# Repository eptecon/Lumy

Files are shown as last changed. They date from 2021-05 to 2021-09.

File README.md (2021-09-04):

Lumy: Smart Connected LED Lighting System
======

Lumy is a smart connected LED lighting system comprising multiple interconnectable modules.

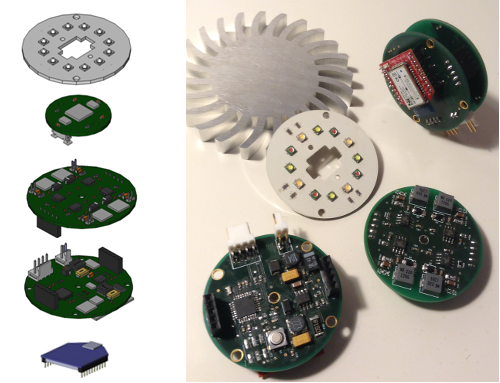
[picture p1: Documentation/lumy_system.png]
 

### Hardware

Lumy hardware comprises following modules:

- LumyCtrl: power supply, main microcontroller (ATMega328P) interface to WiFi module and interface to LED driver
- LumyDrv: 4x TI LM3404 LED driver with 1.2A output each
- LumyLight: LED carrier board, can be populated with up to 12 Cree high power LEDs arranged in 3 separate strings with up to 4 LEDs each
- LumySense: ambient light sensor TSL2591  

### Firmware

Lumy firmware is a simple bare metal C program running on the ATMega328P. It controls the brightness of connected LEDs over PWM inputs of the LED drivers
depending on sensor or user input. The user input is provided over a simple android app, which sends the data wirelessly over WiFi to the Lumy system.

---

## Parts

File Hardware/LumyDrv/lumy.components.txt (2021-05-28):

Stückliste exportiert aus C:/Users/Murzilka/Projektdaten/Eagle/Lumilabs/LumyDrv/lumy.sch am 13.10.2013 14:07:51

Bestückungsvariante: 

Bauteil Wert       Device     Package    Description                                                    
CB1     10n        C-EUC0603  C0603      CAPACITOR, European symbol                                     
CB2     10n        C-EUC0603  C0603      CAPACITOR, European symbol                                     
CB3     10n        C-EUC0603  C0603      CAPACITOR, European symbol                                     
CB4     10n        C-EUC0603  C0603      CAPACITOR, European symbol                                     
CBY1    100n       C-EUC0603  C0603      CAPACITOR, European symbol                                     
CBY2    100n       C-EUC0603  C0603      CAPACITOR, European symbol                                     
CBY3    100n       C-EUC0603  C0603      CAPACITOR, European symbol                                     
CBY4    100n       C-EUC0603  C0603      CAPACITOR, European symbol                                     
CI1     4µ7        C-EUC0603  C0603      CAPACITOR, European symbol                                     
CI2     4µ7        C-EUC0603  C0603      CAPACITOR, European symbol                                     
CI3     4µ7        C-EUC0603  C0603      CAPACITOR, European symbol                                     
CI4     4µ7        C-EUC0603  C0603      CAPACITOR, European symbol                                     
CO1     1µ         C-EUC1206  C1206      CAPACITOR, European symbol                                     
CO2     1µ         C-EUC1206  C1206      CAPACITOR, European symbol                                     
CO3     1µ         C-EUC1206  C1206      CAPACITOR, European symbol                                     
CO4     1µ         C-EUC1206  C1206      CAPACITOR, European symbol                                     
D1      MBRA340T3  MBRA340T3  SMA        Surface Mount Schottky Power Rectifier                         
D2      MBRA340T3  MBRA340T3  SMA        Surface Mount Schottky Power Rectifier                         
D3      MBRA340T3  MBRA340T3  SMA        Surface Mount Schottky Power Rectifier                         
D4      MBRA340T3  MBRA340T3  SMA        Surface Mount Schottky Power Rectifier                         
IC1     LM3404     LM3404     SO08       1A Constant Current Buck  Regulator for driving High Power LEDs
IC2     LM3404     LM3404     SO08       1A Constant Current Buck  Regulator for driving High Power LEDs
IC3     LM3404     LM3404     SO08       1A Constant Current Buck  Regulator for driving High Power LEDs
IC4     LM3404     LM3404     SO08       1A Constant Current Buck  Regulator for driving High Power LEDs
L1      22µ        DR73       DR73       High Power Density, High Efficiency, Shielded Inductors        
L2      22µ        DR73       DR73       High Power Density, High Efficiency, Shielded Inductors        
L3      22µ        DR73       DR73       High Power Density, High Efficiency, Shielded Inductors        
L4      22µ        DR73       DR73       High Power Density, High Efficiency, Shielded Inductors        
RON1    48k7       R-EU_R0805 R0805      RESISTOR, European symbol                                      
RON2    48k7       R-EU_R0805 R0805      RESISTOR, European symbol                                      
RON3    48k7       R-EU_R0805 R0805      RESISTOR, European symbol                                      
RON4    48k7       R-EU_R0805 R0805      RESISTOR, European symbol                                      
RSN1    0R33       R-EU_R1206 R1206      RESISTOR, European symbol                                      
RSN2    0R33       R-EU_R1206 R1206      RESISTOR, European symbol                                      
RSN3    0R33       R-EU_R1206 R1206      RESISTOR, European symbol                                      
RSN4    0R33       R-EU_R1206 R1206      RESISTOR, European symbol                                      
SV1                FE05-1     FE05-1     FEMALE HEADER                                                  
SV2                FE05-1     FE05-1     FEMALE HEADER                                                  
X10     87758-0216 87758-0216 87758-0216 2 Pin - 2mm Dual Row Single Wafer, Vertical T/H HDR            
X20     87758-0216 87758-0216 87758-0216 2 Pin - 2mm Dual Row Single Wafer, Vertical T/H HDR            
X30     87758-0216 87758-0216 87758-0216 2 Pin - 2mm Dual Row Single Wafer, Vertical T/H HDR            
X40     87758-0216 87758-0216 87758-0216 2 Pin - 2mm Dual Row Single Wafer, Vertical T/H HDR

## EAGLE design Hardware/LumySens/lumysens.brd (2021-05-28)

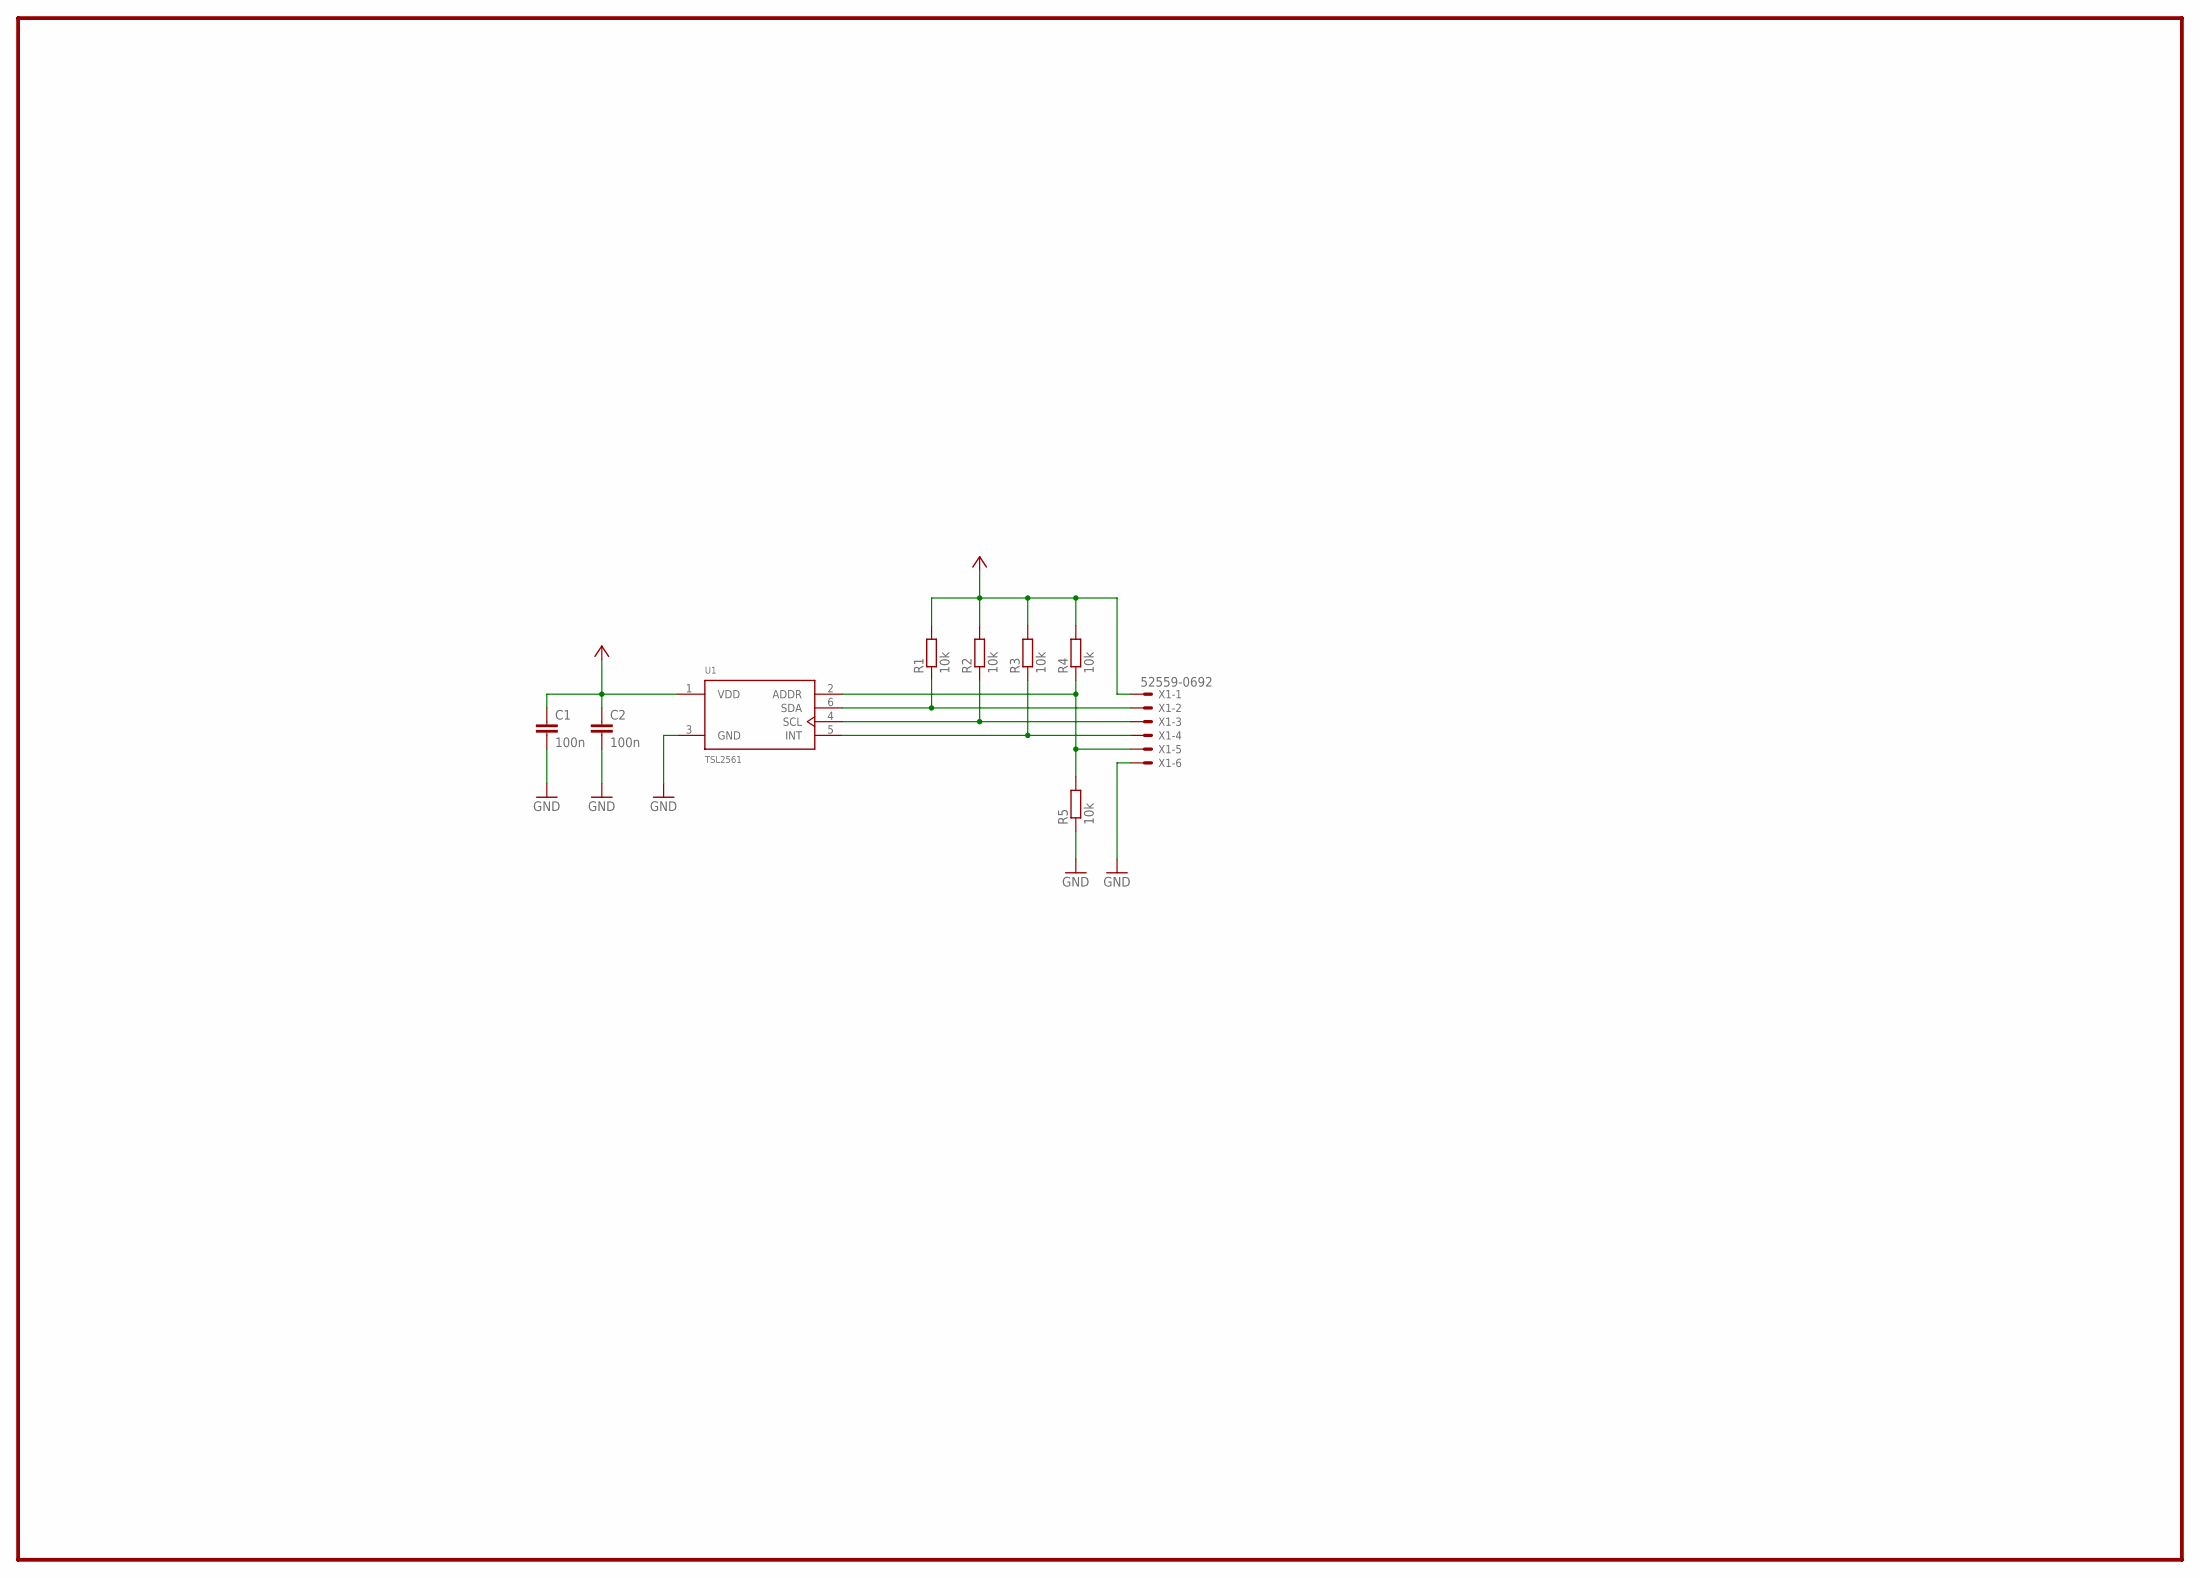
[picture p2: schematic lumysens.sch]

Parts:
C1, C2: 100n; C0603
R1, R2, R3, R4, R5: 10k; R0603
U1: TSL2561; TMB-6
X1: 52559-0692

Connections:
+3V3: C1.1, C2.1, R1.2, R2.2, R3.2, R4.2, U1.1 (VDD), X1.1
GND: C1.2, C2.2, R5.1, U1.3 (GND), X1.6
unnamed: R4.1, R5.2, U1.2 (ADDR), X1.5
unnamed: R1.1, U1.6 (SDA), X1.2
unnamed: R2.1, U1.4 (SCL), X1.3
unnamed: R3.1, U1.5 (INT), X1.4

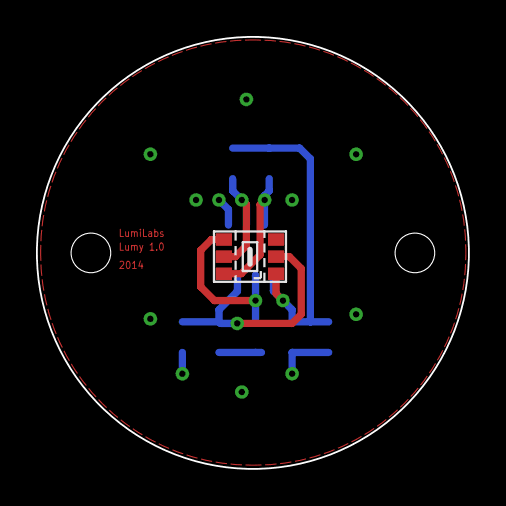
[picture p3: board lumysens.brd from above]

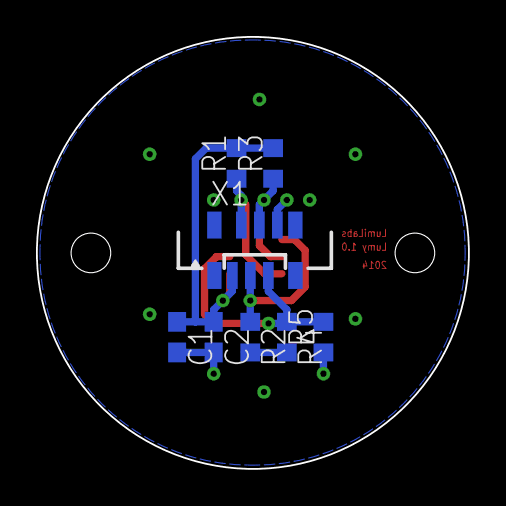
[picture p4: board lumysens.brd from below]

Board: 2 copper layers, 24.0 x 24.0 mm, 9 parts (8 on the bottom side), 6 nets.

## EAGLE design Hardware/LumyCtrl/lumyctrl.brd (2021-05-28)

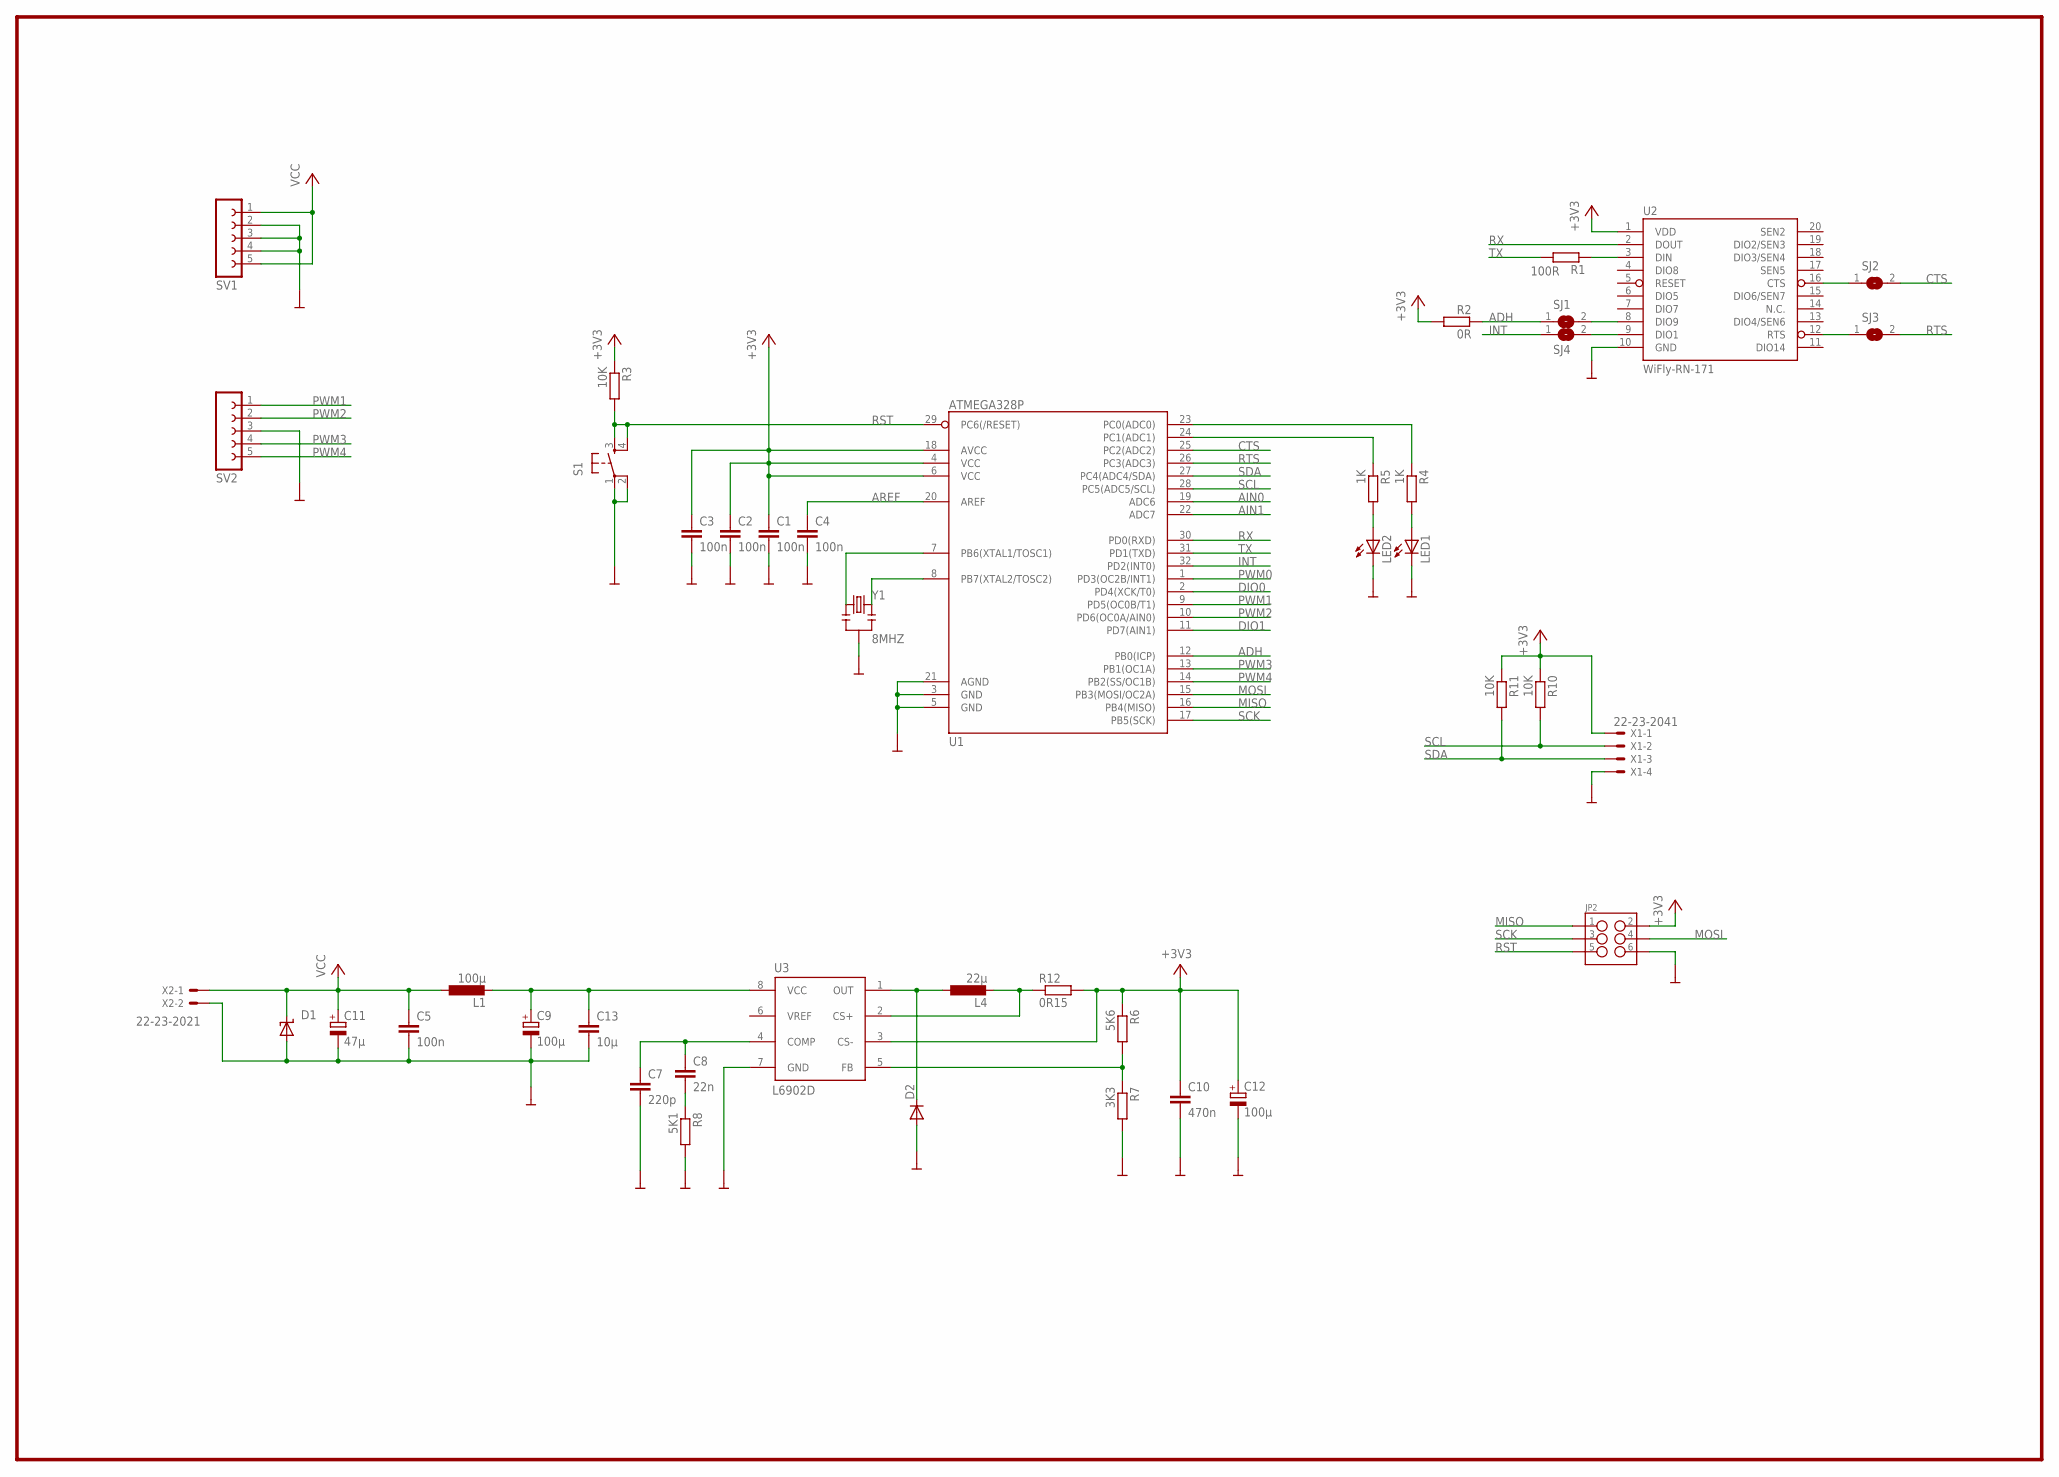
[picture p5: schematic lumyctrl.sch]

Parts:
C1, C2, C3, C4, C5: 100n; C0603
C7: 220p; C0603
C8: 22n; C0603
C9, C12: 100µ; SMC_C
C10: 470n; C0603
C11: 47µ; SMC_E
C13: 10µ; C1206
D1: SUPPRESSOR-SMBJ; SMBJ
D2: DIODESMA; SMA-DIODE
JP2: M03X2SMT; 2X3_SMT_POSTS
L1: 100µ; POWER-CHOKE_WE-TPC
L4: 22µ; POWER-CHOKE_WE-TPC
LED1, LED2: LEDCHIP-LED0603; CHIP-LED0603
R1: 100R; R0603
R2: 0R; R0603
R3, R10, R11: 10K; R0603
R4, R5: 1K; R0603
R6: 5K6; R0603
R7: 3K3; R0603
R8: 5K1; R0603
R12: 0R15; R2512
S1: TAC_SWITCHSMD; TACTILE_SWITCH_SMD
SJ1, SJ2, SJ3, SJ4: SJ
SV1, SV2: FE05-1
U1: ATMEGA328P; TQFP32-08
U2: WiFly-RN-171; XBEE-SMD
U3: L6902D; SO08
X1: 22-23-2041
X2: 22-23-2021
Y1: 8MHZ; RESONATOR-SMD

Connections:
+3V3: C1.1, C2.1, C3.1, C10.1, C12.+, JP2.2, R2.2, R3.1, R6.1, R10.1, R11.1, R12.2, U1.4 (VCC), U1.6 (VCC), U1.18 (AVCC), U2.1 (VDD), U3.3 (CS-), X1.1
ADH: R2.1, SJ1.1, U1.12 (PB0(ICP))
AIN0: U1.19 (ADC6)
AIN1: U1.22 (ADC7)
AREF: C4.1, U1.20 (AREF)
CTS: SJ2.2, U1.25 (PC2(ADC2))
DIO0: U1.2 (PD4(XCK/T0))
DIO1: U1.11 (PD7(AIN1))
GND: C1.2, C2.2, C3.2, C4.2, C5.2, C7.2, C9.-, C10.2, C11.-, C12.-, C13.2, D1.A, D2.A, JP2.6, LED1.C, LED2.C, R7.2, R8.2, S1.1, S1.2, SV1.2, SV1.3, SV1.4, SV2.3, U1.3 (GND), U1.5 (GND), U1.21 (AGND), U2.10 (GND), U3.7 (GND), X1.4, X2.2, Y1.2
INT: SJ4.1, U1.32 (PD2(INT0))
MISO: JP2.1, U1.16 (PB4(MISO))
MOSI: JP2.4, U1.15 (PB3(MOSI/OC2A))
unnamed: R1.1, U2.3 (DIN)
unnamed: SJ1.2, U2.8 (DIO9)
unnamed: D2.C, L4.1, U3.1 (OUT)
unnamed: U1.7 (PB6(XTAL1/TOSC1)), Y1.1
unnamed: U1.8 (PB7(XTAL2/TOSC2)), Y1.3
unnamed: SJ3.1, U2.12 (RTS)
unnamed: SJ2.1, U2.16 (CTS)
unnamed: R6.2, R7.1, U3.5 (FB)
unnamed: C9.+, C13.1, L1.2, U3.8 (VCC)
unnamed: C7.1, C8.1, U3.4 (COMP)
unnamed: LED2.A, R5.2
unnamed: C8.2, R8.1
unnamed: LED1.A, R4.2
unnamed: R4.1, U1.23 (PC0(ADC0))
unnamed: R5.1, U1.24 (PC1(ADC1))
unnamed: L4.2, R12.1, U3.2 (CS+)
unnamed: SJ4.2, U2.9 (DIO1)
PWM0: U1.1 (PD3(OC2B/INT1))
PWM1: SV2.1, U1.9 (PD5(OC0B/T1))
PWM2: SV2.2, U1.10 (PD6(OC0A/AIN0))
PWM3: SV2.4, U1.13 (PB1(OC1A))
PWM4: SV2.5, U1.14 (PB2(SS/OC1B))
RST: JP2.5, R3.2, S1.3, S1.4, U1.29 (PC6(/RESET))
RTS: SJ3.2, U1.26 (PC3(ADC3))
RX: U1.30 (PD0(RXD)), U2.2 (DOUT)
SCK: JP2.3, U1.17 (PB5(SCK))
SCL: R10.2, U1.28 (PC5(ADC5/SCL)), X1.2
SDA: R11.2, U1.27 (PC4(ADC4/SDA)), X1.3
TX: R1.2, U1.31 (PD1(TXD))
VCC: C5.1, C11.+, D1.C, L1.1, SV1.1, SV1.5, X2.1

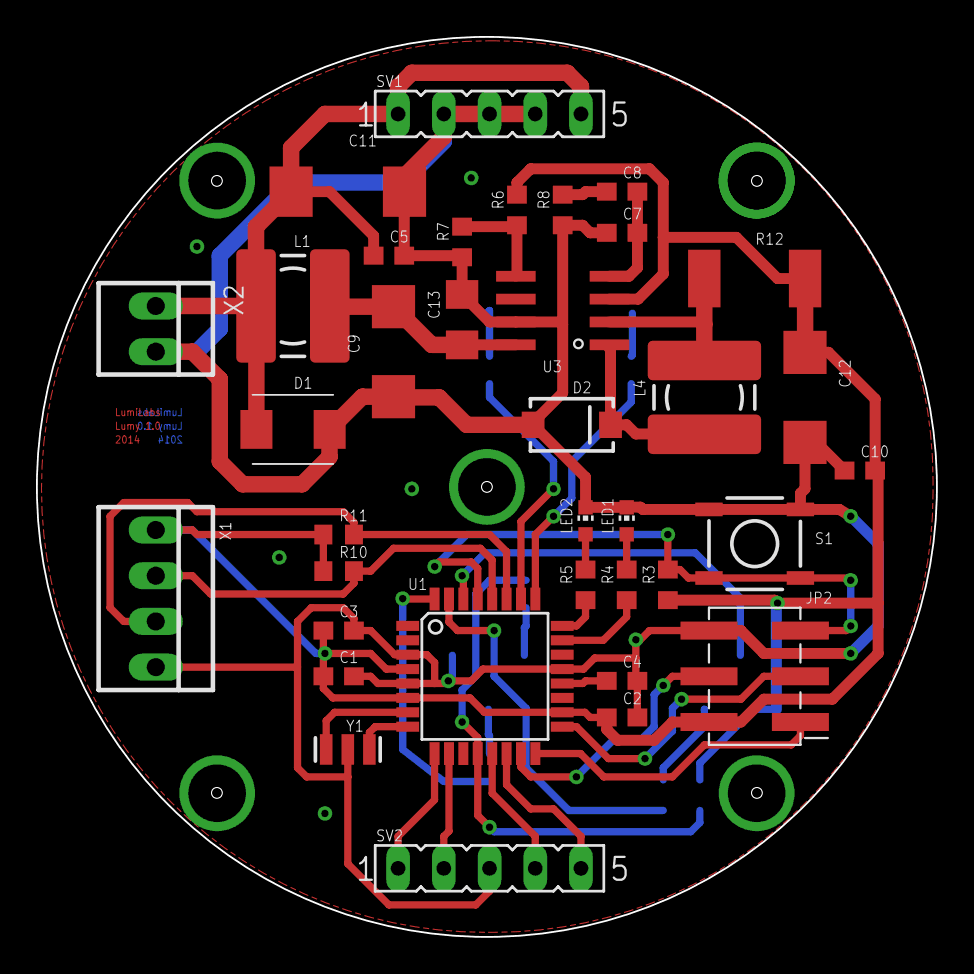
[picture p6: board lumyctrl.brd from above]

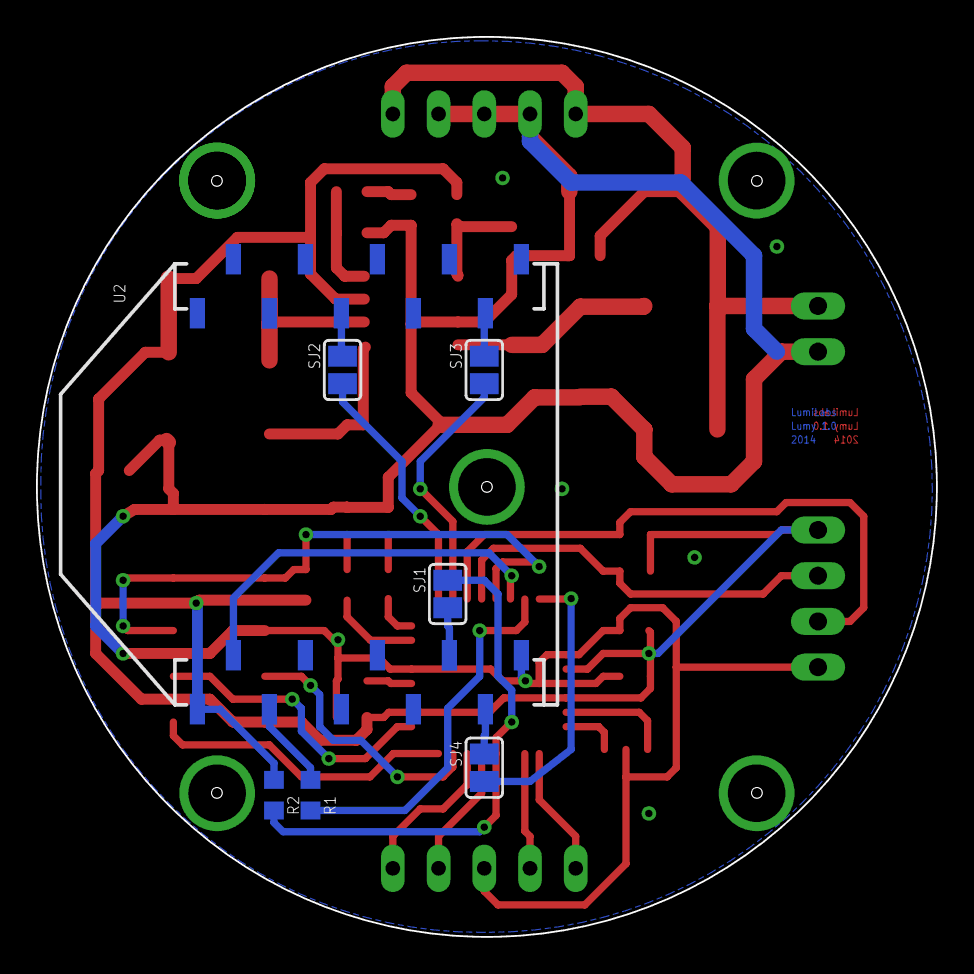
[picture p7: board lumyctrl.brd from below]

Board: 2 copper layers, 50.0 x 50.0 mm, 43 parts (7 on the bottom side), 37 nets.

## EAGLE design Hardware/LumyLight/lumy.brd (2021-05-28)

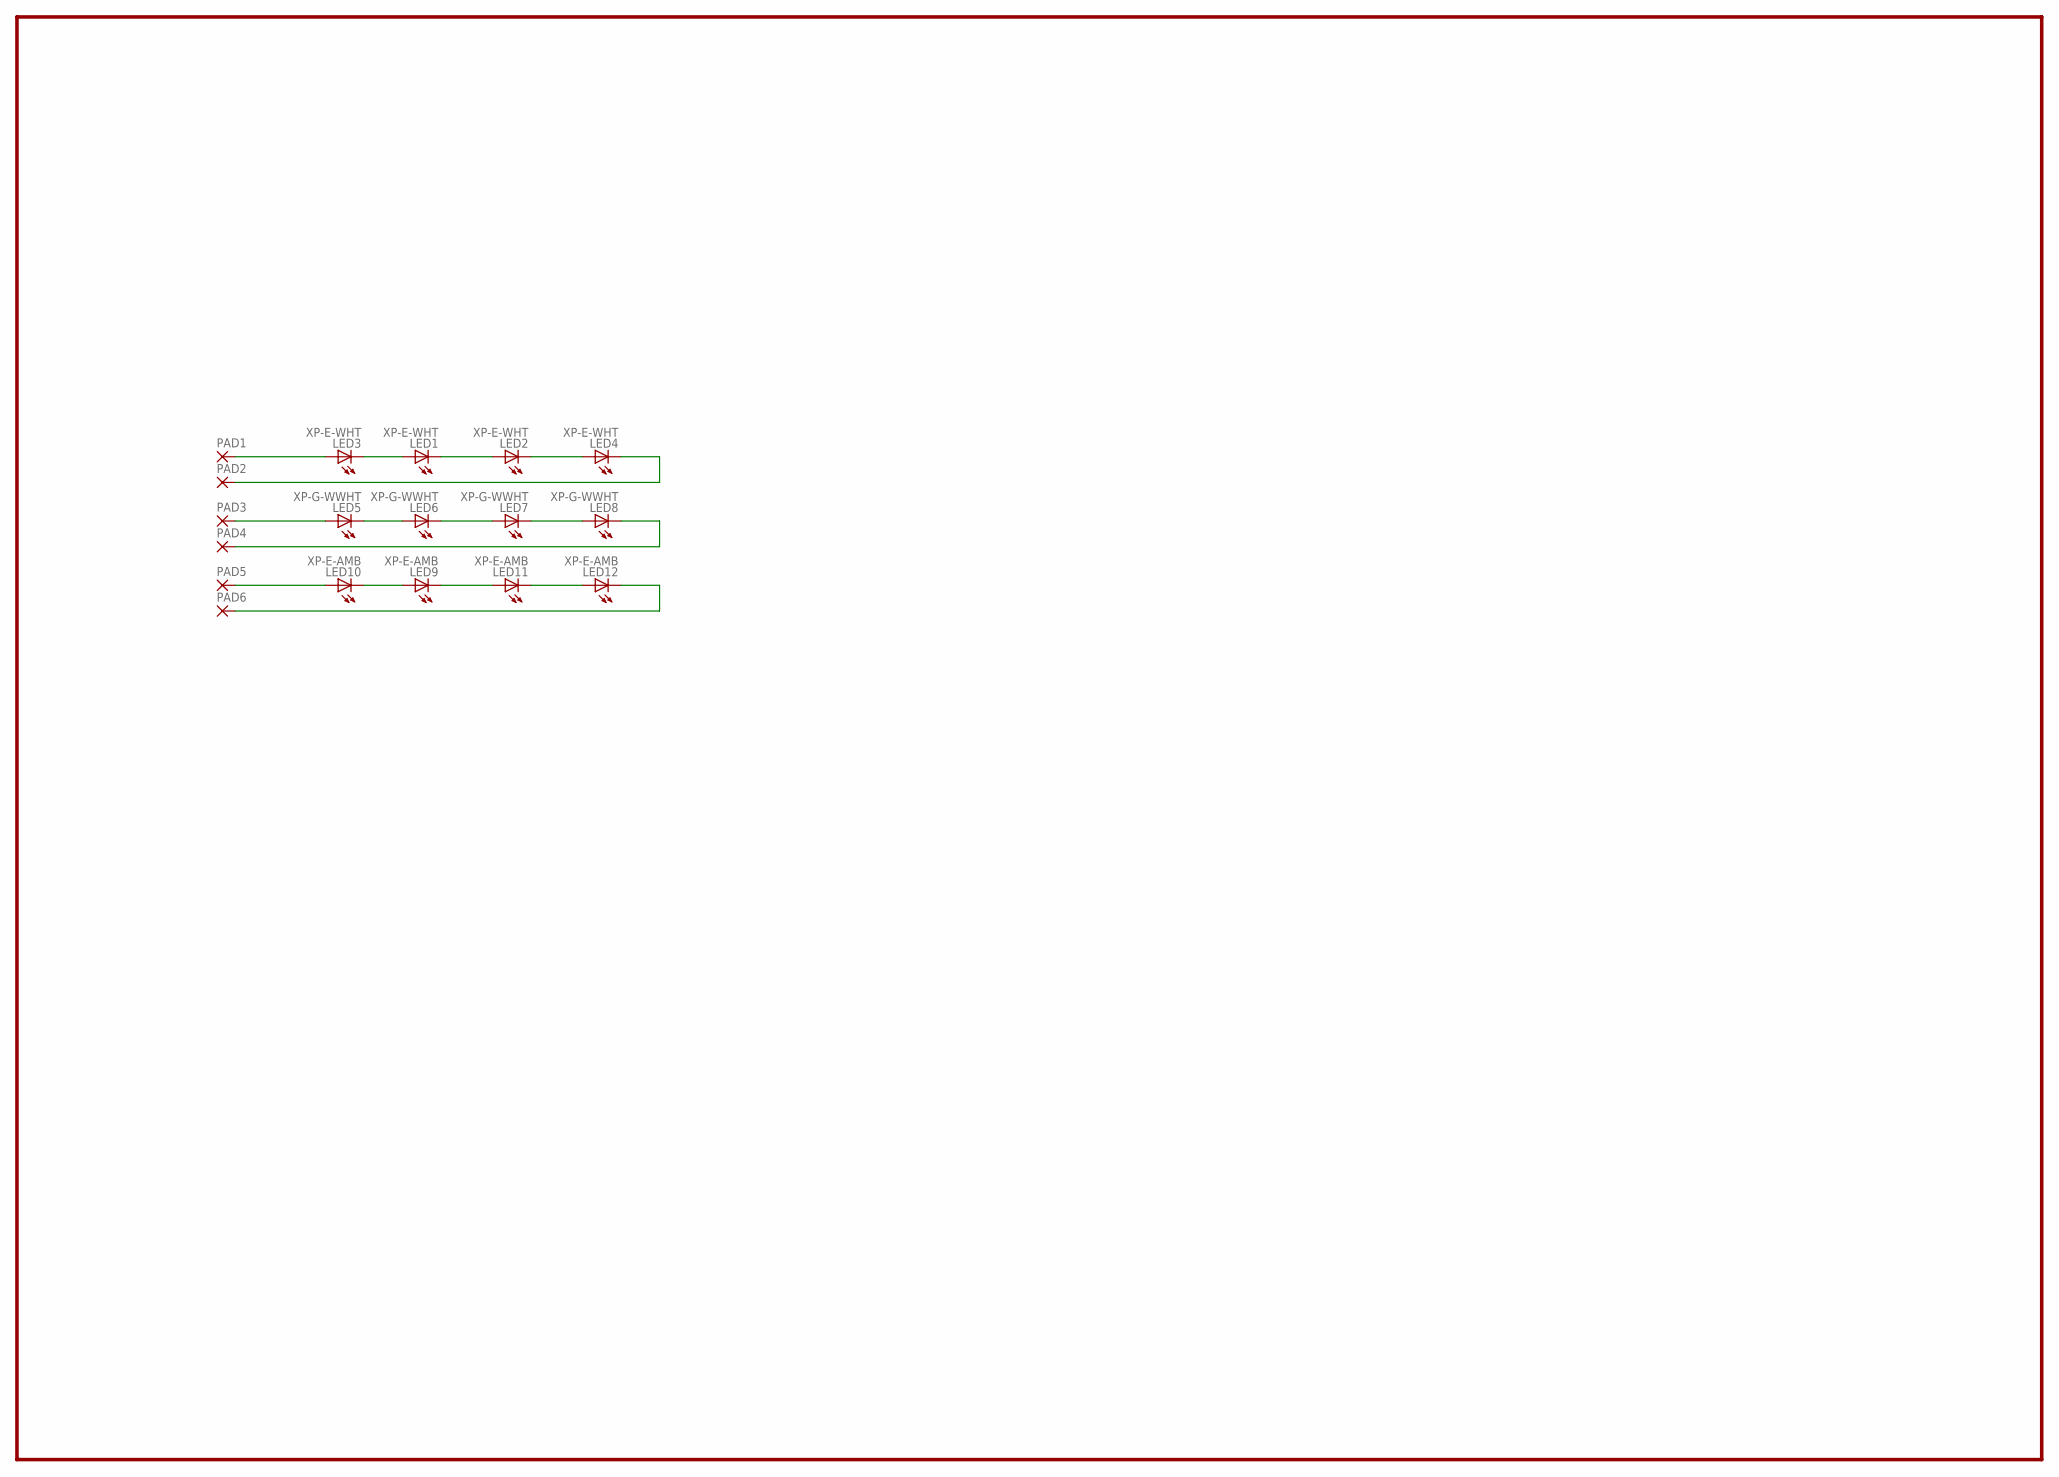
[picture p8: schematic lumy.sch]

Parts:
LED1, LED2, LED3, LED4: XP-E-WHT; CREE_XLAMP
LED5, LED6, LED7, LED8: XP-G-WWHT; CREE_XLAMP
LED9, LED10, LED11, LED12: XP-E-AMB; CREE_XLAMP
PAD1, PAD2, PAD3, PAD4, PAD5, PAD6: SMD2; SMD1,27-2,54

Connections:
unnamed: LED1.A, LED1.A@1 (A), LED3.C, LED3.C@1 (C)
unnamed: LED1.C, LED1.C@1 (C), LED2.A, LED2.A@1 (A)
unnamed: LED2.C, LED2.C@1 (C), LED4.A, LED4.A@1 (A)
unnamed: LED7.C, LED7.C@1 (C), LED8.A, LED8.A@1 (A)
unnamed: LED6.C, LED6.C@1 (C), LED7.A, LED7.A@1 (A)
unnamed: LED5.C, LED5.C@1 (C), LED6.A, LED6.A@1 (A)
unnamed: LED3.A, LED3.A@1 (A), PAD1.1
unnamed: LED9.A, LED9.A@1 (A), LED10.C, LED10.C@1 (C)
unnamed: LED9.C, LED9.C@1 (C), LED11.A, LED11.A@1 (A)
unnamed: LED11.C, LED11.C@1 (C), LED12.A, LED12.A@1 (A)
unnamed: LED4.C, LED4.C@1 (C), PAD2.1
unnamed: LED5.A, LED5.A@1 (A), PAD3.1
unnamed: LED8.C, LED8.C@1 (C), PAD4.1
unnamed: LED10.A, LED10.A@1 (A), PAD5.1
unnamed: LED12.C, LED12.C@1 (C), PAD6.1

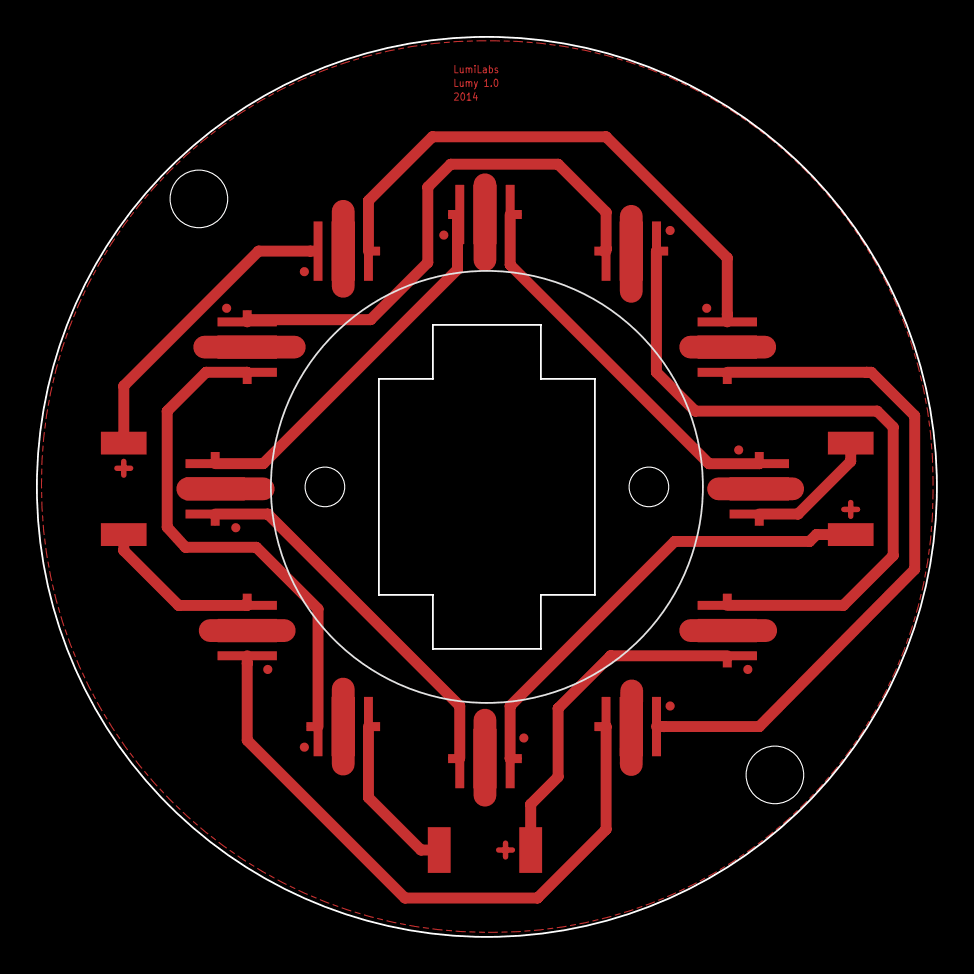
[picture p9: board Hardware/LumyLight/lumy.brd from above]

Board: 2 copper layers, 50.0 x 50.0 mm, 18 parts (0 on the bottom side), 15 nets.

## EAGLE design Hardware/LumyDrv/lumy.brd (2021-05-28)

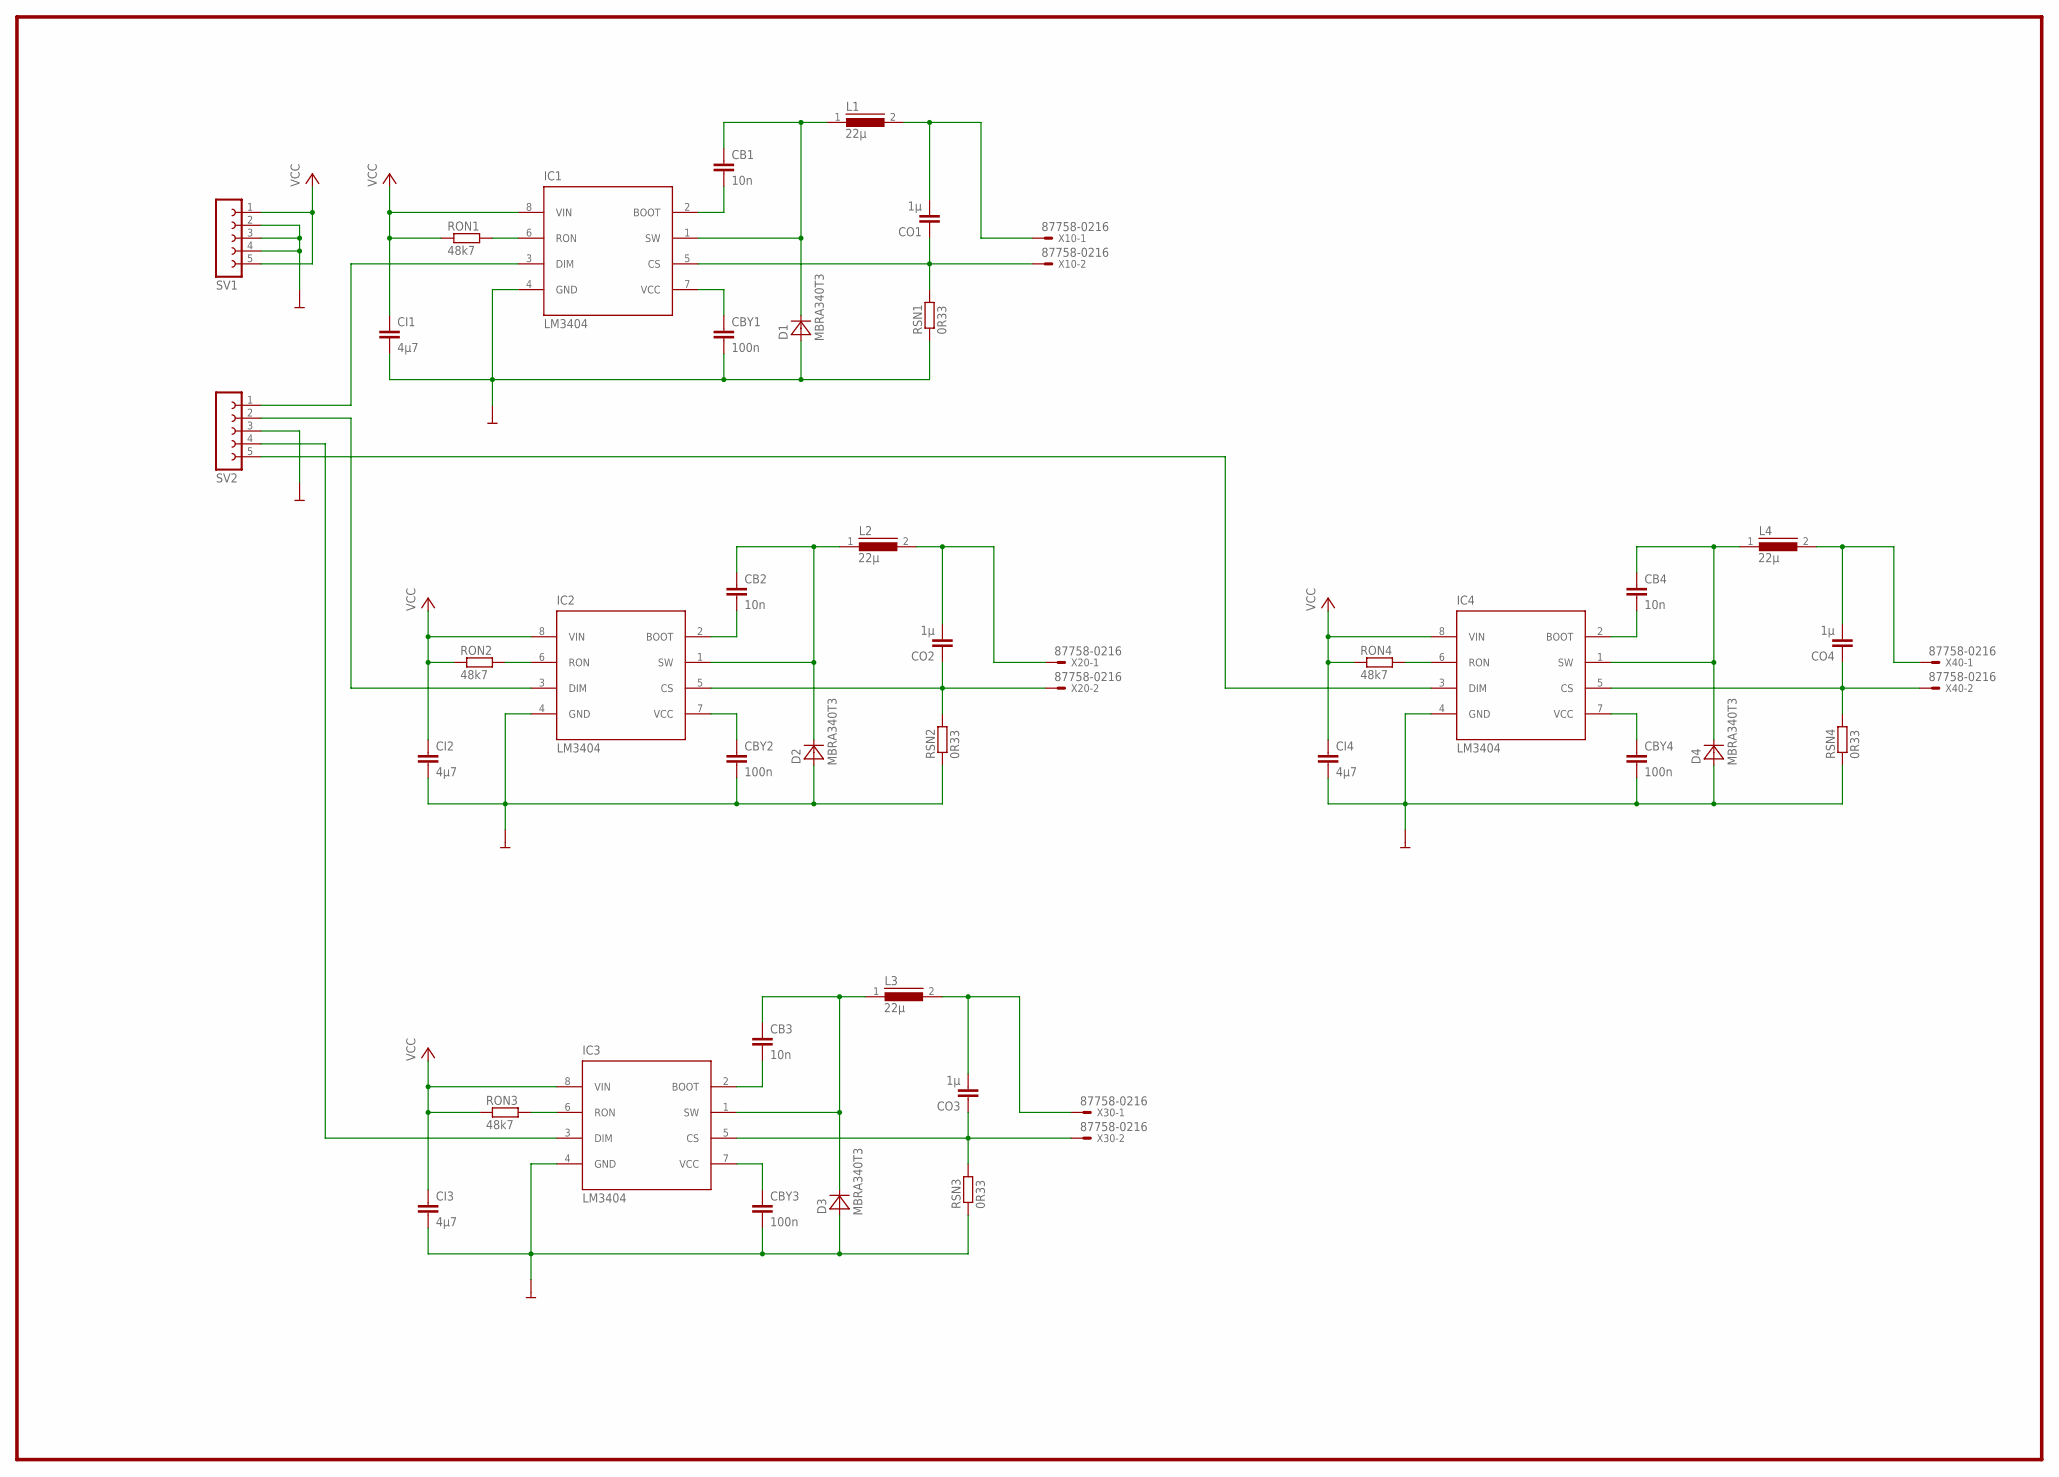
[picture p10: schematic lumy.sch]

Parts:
CB1, CB2, CB3, CB4: 10n; C0603
CBY1, CBY2, CBY3, CBY4: 100n; C0603
CI1, CI2, CI3, CI4: 4µ7; C0603
CO1, CO2, CO3, CO4: 1µ; C1206
D1, D2, D3, D4: MBRA340T3; SMA
IC1, IC2, IC3, IC4: LM3404; SO08
L1, L2, L3, L4: 22µ; DR73
RON1, RON2, RON3, RON4: 48k7; R0805
RSN1, RSN2, RSN3, RSN4: 0R33; R1206
SV1, SV2: FE05-1
X10, X20, X30: 87758-0216
X40: 87758-0216; MPN 87758-0216

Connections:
GND: CBY1.2, CBY2.2, CBY3.2, CBY4.2, CI1.2, CI2.2, CI3.2, CI4.2, D1.A, D2.A, D3.A, D4.A, IC1.4 (GND), IC2.4 (GND), IC3.4 (GND), IC4.4 (GND), RSN1.1, RSN2.1, RSN3.1, RSN4.1, SV1.2, SV1.3, SV1.4, SV2.3
unnamed: IC1.6 (RON), RON1.2
unnamed: CB1.1, D1.C, IC1.1 (SW), L1.1
unnamed: CBY1.1, IC1.7 (VCC)
unnamed: CO1.1, IC1.5 (CS), RSN1.2, X10.2
unnamed: CO1.2, L1.2, X10.1
unnamed: CB1.2, IC1.2 (BOOT)
unnamed: IC1.3 (DIM), SV2.1
unnamed: IC2.6 (RON), RON2.2
unnamed: CBY2.1, IC2.7 (VCC)
unnamed: CO2.1, IC2.5 (CS), RSN2.2, X20.2
unnamed: CO2.2, L2.2, X20.1
unnamed: CB2.1, D2.C, IC2.1 (SW), L2.1
unnamed: CB2.2, IC2.2 (BOOT)
unnamed: IC2.3 (DIM), SV2.2
unnamed: IC3.6 (RON), RON3.2
unnamed: CBY3.1, IC3.7 (VCC)
unnamed: CO3.1, IC3.5 (CS), RSN3.2, X30.2
unnamed: CO3.2, L3.2, X30.1
unnamed: CB3.1, D3.C, IC3.1 (SW), L3.1
unnamed: CB3.2, IC3.2 (BOOT)
unnamed: IC3.3 (DIM), SV2.4
unnamed: CBY4.1, IC4.7 (VCC)
unnamed: CB4.2, IC4.2 (BOOT)
unnamed: IC4.6 (RON), RON4.2
unnamed: CB4.1, D4.C, IC4.1 (SW), L4.1
unnamed: CO4.2, L4.2, X40.1
unnamed: CO4.1, IC4.5 (CS), RSN4.2, X40.2
unnamed: IC4.3 (DIM), SV2.5
VCC: CI1.1, CI2.1, CI3.1, CI4.1, IC1.8 (VIN), IC2.8 (VIN), IC3.8 (VIN), IC4.8 (VIN), RON1.1, RON2.1, RON3.1, RON4.1, SV1.1, SV1.5

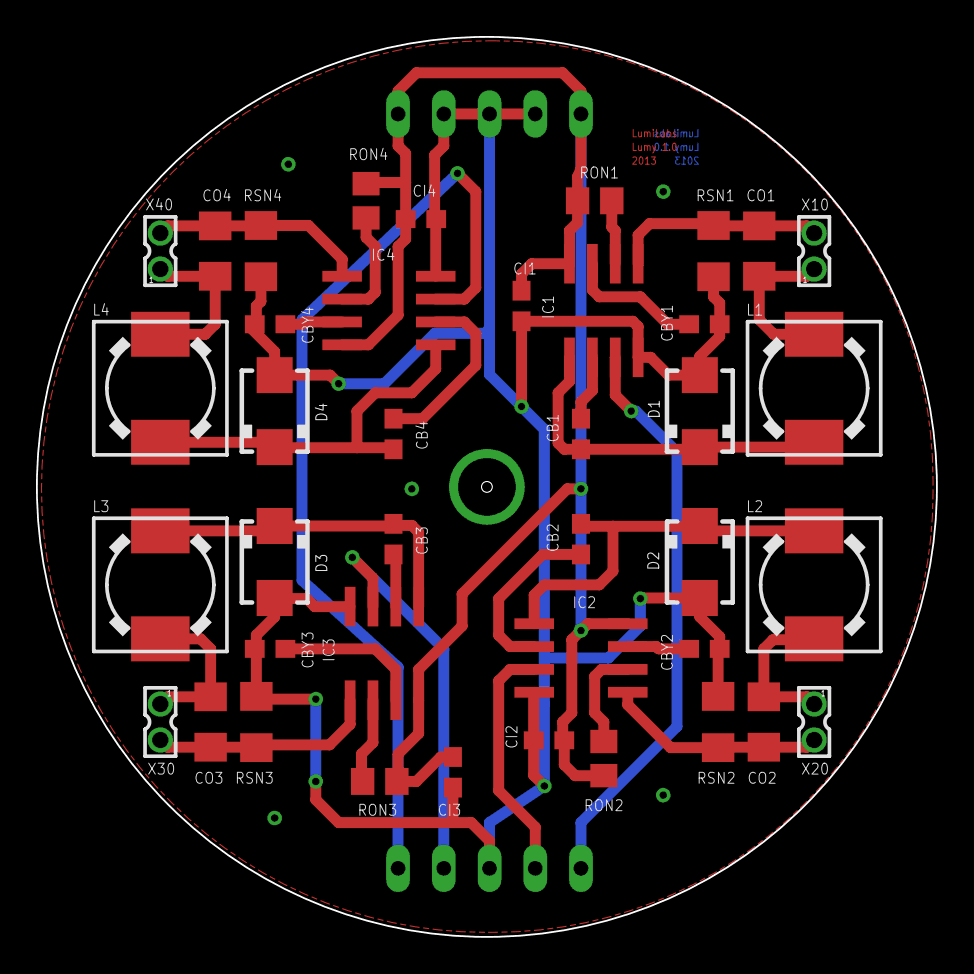
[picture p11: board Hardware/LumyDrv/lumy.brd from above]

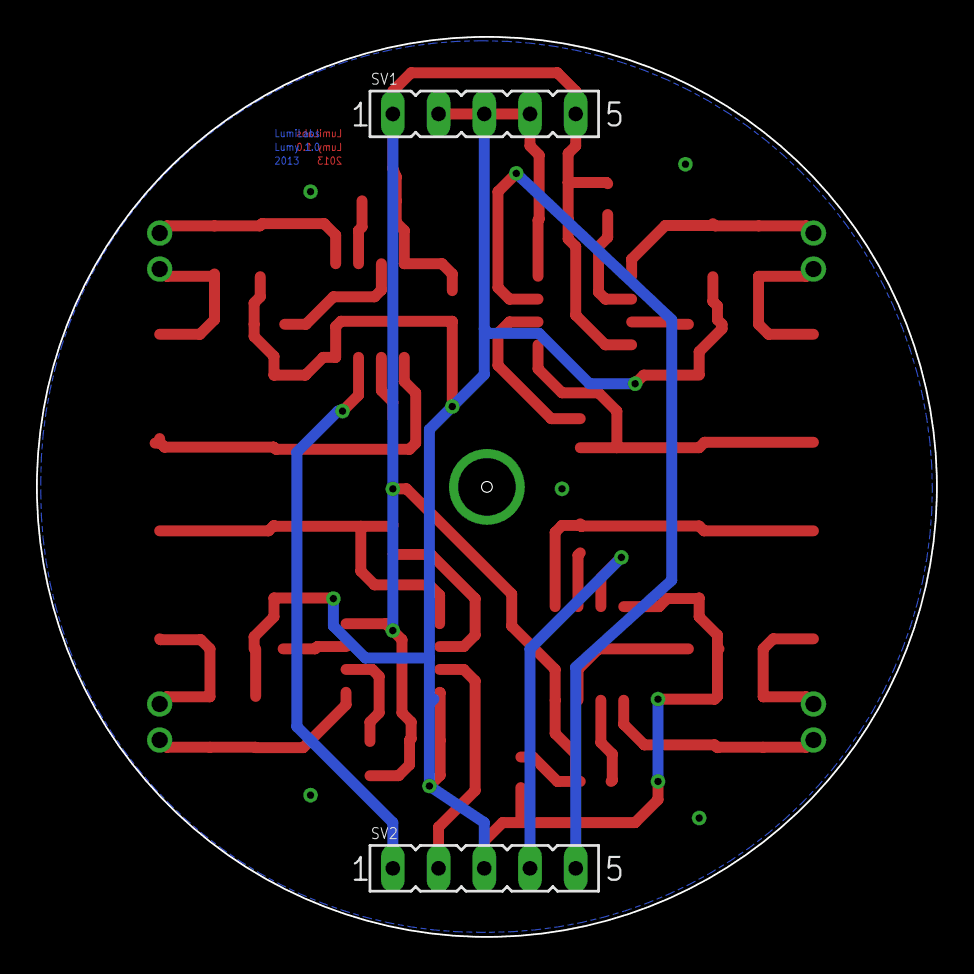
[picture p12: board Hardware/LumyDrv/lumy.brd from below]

Board: 2 copper layers, 50.0 x 50.0 mm, 42 parts (2 on the bottom side), 30 nets.

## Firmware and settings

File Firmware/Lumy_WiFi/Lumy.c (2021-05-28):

/*************************************************************************
Title:    Lumy Control - Control of 3x TI LM3404 LED Driver over WiFi with Wifly module (RN-VX)
Author:   EP
File:     $Id: Lumy.c,v 1.0 2014/07/10 11:46:30 $
Software: AVR-GCC 4.1
Hardware: ATmega328P at 8 Mhz, 


*************************************************************************/
#include <stdlib.h>
#include <avr/io.h>
#include <avr/interrupt.h>
#include <avr/pgmspace.h>
#include <util/delay.h>
#include <stdint.h>
#include <string.h>
#include "uart.h"
#include "wifly1.h"

/* define CPU frequency in Mhz here if not defined in Makefile */
#ifndef F_CPU
#define F_CPU 8000000UL
#endif

/* 9600 baud */
#define UART_BAUD_RATE    9600

/* End of line */
#define CR "\r\n"
#define ZERO "\n"

// LED Defines
#define LED_DDR     DDRD        // DDRA, DDRB...
#define LED_PORT    PORTD       // PORTA, PORTB...
#define LED_PORTPIN PD2         // PA0, PA1..., PB0, ...

#define INVERT_PWM 0//(1 << COM1A0)


#define BODY_BUFFER_SIZE 64
#define BUFFER_SIZE 8



//Prototypen
void uart_gets(char *Buffer, int Size);
void uart_Debug(char *Buffer, int Size);

//Globale Variablen
char rxBuffer[BODY_BUFFER_SIZE];
char commBuffer[BUFFER_SIZE];
unsigned char flag_ISDNewData = 0;
unsigned char flag_WaitForData = 0;
unsigned char flag_Steuerung = 0;
char responseBuffer[BODY_BUFFER_SIZE];
unsigned char step = 0;
const char FixedPrompt[] = "CMD";
unsigned int Grafzahl; 
unsigned int ergebnis;
int Size;


// 10-Bit PWM with 64 different settings
 
void pwm_10_64_1 (int8_t LightVal1)
{ 
    // 10 Bit Fast PWM
    TCCR0A = 0x83 | INVERT_PWM;
    // prescaler 64 -> ~122 Hz PWM frequency
    TCCR0B = 0x03;//(1 << WGM02) | 3;
 
 	OCR0A = LightVal1;
    //pwm_up_down (pwmtable_10, 64, delay);
}

//void pwm_10_64_2 (int16_t LightVal2)
//{ 
    // 10 Bit Fast PWM
//    TCCR1A = 0x83 | INVERT_PWM;
    // prescaler 64 -> ~122 Hz PWM frequency
//    TCCR1B = (1 << WGM12) | 3;
 
// 	OCR1A = LightVal2;
    //pwm_up_down (pwmtable_10, 64, delay);
//} 

void pwm_10_64_3 (int16_t LightVal2, int16_t LightVal3 )
{ 
    // 10 Bit Fast PWM
    TCCR1A = 0xA3 | INVERT_PWM;
    // prescaler 64 -> ~122 Hz PWM frequency
    TCCR1B = (1 << WGM12) | 3;
 
 	OCR1A = LightVal2;
 	OCR1B = LightVal3;
    //pwm_up_down (pwmtable_10, 64, delay);
} 

int main(void)
{
  

    //LED_DDR |= (1<<LED_PORTPIN);
	DDRC = 0x02;
	DDRD = 0x68;
	DDRB = 0x06;

    uart_init( UART_BAUD_SELECT_DOUBLE_SPEED(UART_BAUD_RATE,F_CPU) );
    sei();

	uart_flush();
	_delay_ms(300);
	uart_puts("$$$");
	uart_flush();
	//	uart_puts("\r");	
	//_delay_ms(300);
	//uart_puts("$$$");
	//uart_flush();
	
	while(1)
	{	
		PORTC |= (1<<PC1);	
		
		if( uart_available() > 0 )
		{					
			uart_gets(rxBuffer, BODY_BUFFER_SIZE);
			//uart_Debug(rxBuffer, BODY_BUFFER_SIZE);
			
			if (strcmp(rxBuffer, "CMD") == 0)
			{
				LED_PORT &= ~(1<<LED_PORTPIN);
				flag_WaitForData = 1;
				uart_flush();
			}	
			
			if (strcmp(rxBuffer, "<2.30>") == 0)
			{
				LED_PORT &= ~(1<<LED_PORTPIN);
				flag_ISDNewData = 1;
				uart_flush();
			}

			if (strcmp(rxBuffer, "*OPEN*") == 0)
			{
				flag_Steuerung = 1;
				uart_flush();
			}
        }
	
		if(flag_WaitForData == 1)
		//rxBuffer[count] = '\0';
		//uart_puts("OK4");
		//uart_puts("\n");
		{
			LED_PORT |= (1<<LED_PORTPIN);
      		//flag_ISDNewData = 1;
			uart_flush();
			_delay_ms(1000);
			uart_puts("set wlan ssd htc\r");
		    flag_WaitForData = 0;
			//	uart_puts("\r");	
			//}

		}
  		
		if(flag_ISDNewData == 1)
		//rxBuffer[count] = '\0';
		//uart_puts("OK4");
		//uart_puts("\n");
		{
		    //LED_PORT |= (1<<LED_PORTPIN);
      	    //flag_ISDNewData = 1;
		    uart_flush();
		    _delay_ms(1000);
		    uart_puts("exit\r");
			flag_ISDNewData = 0;
		}

		while(flag_Steuerung == 1)
		//rxBuffer[count] = '\0';
		//uart_puts("OK4");
		//uart_puts("\n");
		{
			//LED_PORT |= (1<<LED_PORTPIN);
			if( uart_available() >0 )
			{					
				uart_gets(commBuffer, BUFFER_SIZE);
				//uart_Debug(commBuffer, BUFFER_SIZE);				

				if (atoi(commBuffer) != 0)
				{
					//LED_PORT &= ~(1<<LED_PORTPIN);
    	  			//flag_ISDNewData = 1;
					//uart_puts("LED_AN!");
					Grafzahl = atoi(commBuffer);
					ergebnis = Grafzahl * 10;
					itoa(ergebnis, responseBuffer, 10);
					//PORTB |= (1<<PB1);//LED_PORTPIN);
					pwm_10_64_1 (ergebnis);
					pwm_10_64_3 (ergebnis, ergebnis);
					uart_puts(responseBuffer);
					//uart_puts("\r");
					uart_flush();
				}
				else
				{
					//PORTB &= ~(1<<PB1);
					//LED_PORT &= ~(1<<LED_PORTPIN);
					pwm_10_64_1 (0);
					pwm_10_64_3 (0,0);
					uart_flush();
				}	
			}

		}	

  	}
}


/* Diese Funktion sammelt Zeichen aus dem uart-Ringbuffer ein bis ein End of String (\r) empfangen wird 
und schreibt sie in ein Array bis das Array gefüllt wird.*/
void uart_gets(char *Buffer, int Size)
{
	unsigned int nextChar = 0;
	int count = 0;	
	
	//if(uart_available > 0)
	//{					
		//_delay_ms(10);

		while(count < Size-1)
		{	
			nextChar = uart_getc();
			_delay_ms(5);
			
			if (nextChar != '\r' && nextChar != '\n')
			{	
			Buffer[count] = nextChar;
			count++;
			}
		}
		count = 0;
		uart_flush();
	//}
}/*uart_gets*/


/* Dies Funktion schreibt Zeichenweise den Inhalt des Arrays in den uart-Ringbuffer, 
wenn der Inhalt ungleich Null ist. */
void uart_Debug(char *Buffer, int Size)
{
	int count = 0;

	if (*Buffer != '\0' )
	{	
		while( count <  Size )
		{
			uart_putc(Buffer[count]);
			count++;
		}
		count = 0;
		uart_putc('\r');
		//uart_puts(rxBuffer);
		//uart_putc('\r');
	}
}/*uart_Debug*/

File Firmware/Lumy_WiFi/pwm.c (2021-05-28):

//**************************************************************************
//*
//*  LED fading test
//*  uses exponential PWM settings to achive visual linear brightness
//*
//*  ATmega32 @ 8 MHz
//*                  
//**************************************************************************
 
#include <avr/io.h>
#include <avr/pgmspace.h>
 
#define F_CPU 8000000L
#include <util/delay.h>
 
#define STK500 0
 
#if STK500
// inverted PWM on OC1A for STK500
#define INVERT_PWM (1 << COM1A0)
#else
// non-inverted PWM on OC1A
#define INVERT_PWM 0
#endif // STK500
 
const uint16_t pwmtable_8A[4]  PROGMEM = { 0, 16, 64, 255 };
const uint16_t pwmtable_8B[8]  PROGMEM =
{
    0, 4, 8, 16, 32, 64, 128, 255
};
 
const uint16_t pwmtable_8C[16] PROGMEM =
{
    0, 2, 3, 4, 6, 8, 11, 16, 23, 32, 45, 64, 90, 128, 181, 255
};
 
const uint16_t pwmtable_8D[32] PROGMEM =
{
    0, 1, 2, 2, 2, 3, 3, 4, 5, 6, 7, 8, 10, 11, 13, 16, 19, 23,
    27, 32, 38, 45, 54, 64, 76, 91, 108, 128, 152, 181, 215, 255
};
 
const uint16_t pwmtable_10[64] PROGMEM =
{
    0, 1, 1, 2, 2, 2, 2, 2, 3, 3, 3, 4, 4, 5, 5, 6, 6, 7, 8, 9, 10,
    11, 12, 13, 15, 17, 19, 21, 23, 26, 29, 32, 36, 40, 44, 49, 55,
    61, 68, 76, 85, 94, 105, 117, 131, 146, 162, 181, 202, 225, 250,
    279, 311, 346, 386, 430, 479, 534, 595, 663, 739, 824, 918, 1023
};
 
const uint16_t pwmtable_16[256] PROGMEM =
{
    0, 1, 1, 1, 1, 1, 1, 1, 1, 2, 2, 2, 2, 2, 2, 2, 2, 2, 2, 2, 2, 3,
    3, 3, 3, 3, 3, 3, 4, 4, 4, 4, 4, 4, 5, 5, 5, 5, 5, 6, 6, 6, 6, 7,
    7, 7, 8, 8, 8, 9, 9, 10, 10, 10, 11, 11, 12, 12, 13, 13, 14, 15,
    15, 16, 17, 17, 18, 19, 20, 21, 22, 23, 24, 25, 26, 27, 28, 29,
    31, 32, 33, 35, 36, 38, 40, 41, 43, 45, 47, 49, 52, 54, 56, 59,
    61, 64, 67, 70, 73, 76, 79, 83, 87, 91, 95, 99, 103, 108, 112,
    117, 123, 128, 134, 140, 146, 152, 159, 166, 173, 181, 189, 197,
    206, 215, 225, 235, 245, 256, 267, 279, 292, 304, 318, 332, 347,
    362, 378, 395, 412, 431, 450, 470, 490, 512, 535, 558, 583, 609,
    636, 664, 693, 724, 756, 790, 825, 861, 899, 939, 981, 1024, 1069,
    1117, 1166, 1218, 1272, 1328, 1387, 1448, 1512, 1579, 1649, 1722,
    1798, 1878, 1961, 2048, 2139, 2233, 2332, 2435, 2543, 2656, 2773,
    2896, 3025, 3158, 3298, 3444, 3597, 3756, 3922, 4096, 4277, 4467,
    4664, 4871, 5087, 5312, 5547, 5793, 6049, 6317, 6596, 6889, 7194,
    7512, 7845, 8192, 8555, 8933, 9329, 9742, 10173, 10624, 11094,
    11585, 12098, 12634, 13193, 13777, 14387, 15024, 15689, 16384,
    17109, 17867, 18658, 19484, 20346, 21247, 22188, 23170, 24196,
    25267, 26386, 27554, 28774, 30048, 31378, 32768, 34218, 35733,
    37315, 38967, 40693, 42494, 44376, 46340, 48392, 50534, 52772,
    55108, 57548, 60096, 62757, 65535
};
 
// long, variable delays
 
void my_delay (uint16_t milliseconds)
{
    for (; milliseconds > 0; milliseconds--)
        _delay_ms (1);
}
 
 
void pwm_up_down (const uint16_t pwm_table[], int16_t size, uint16_t delay)
{
    int16_t tmp;
 
    for (tmp = 0; tmp < size; tmp++)
    {
        OCR1A = pgm_read_word (& pwm_table[tmp]);
        my_delay (delay);
    }
 
    for (tmp = size-1; tmp >= 0; tmp--)
    {
        OCR1A = pgm_read_word (& pwm_table[tmp]);
        my_delay (delay);
    }
}
 
// 8-Bit PWM with only 4 different settings
 
void pwm_8_4 (uint16_t delay)
{
    // 8 Bit Fast PWM
    TCCR1A = 0x81 | INVERT_PWM;
    // prescaler 256 -> ~122 Hz PWM frequency
    TCCR1B = (1 << WGM12) | 4;
    
    pwm_up_down (pwmtable_8A, 4, delay);
}
 
// 8-Bit PWM with 8 different settings
 
void pwm_8_8 (uint16_t delay)
{
    // 8 Bit Fast PWM
    TCCR1A = 0x81 | INVERT_PWM;
    // prescaler 256 -> ~122 Hz PWM frequency
    TCCR1B = (1 << WGM12) | 4;
 
    pwm_up_down (pwmtable_8B, 8, delay);
}
 
// 8-Bit PWM with 16 different settings
 
void pwm_8_16 (uint16_t delay)
{
    // 8 Bit Fast PWM
    TCCR1A = 0x81 | INVERT_PWM;
    // prescaler 256 -> ~122 Hz PWM frequency
    TCCR1B = (1 << WGM12) | 4;
 
    pwm_up_down (pwmtable_8C, 16, delay);
}
 
// 8-Bit PWM with 32 different settings
 
void pwm_8_32 (uint16_t delay)
{
    //  8 Bit Fast PWM
    TCCR1A = 0x81 | INVERT_PWM;
    // prescaler 256 -> ~122 Hz PWM frequency
    TCCR1B = (1 << WGM12) | 4;
 
    pwm_up_down (pwmtable_8D, 32, delay);
}
 
// 10-Bit PWM with 64 different settings
 
void pwm_10_64 (uint16_t delay)
{ 
    // 10 Bit Fast PWM
    TCCR1A = 0x83 | INVERT_PWM;
    // prescaler 64 -> ~122 Hz PWM frequency
    TCCR1B = (1 << WGM12) | 3;
 
    pwm_up_down (pwmtable_10, 64, delay);
}
 
// 16-Bit PWM with 256 different settings
 
void pwm_16_256 (uint16_t delay)
{
    // 16 Bit Fast PWM
    TCCR1A = 0x82 | INVERT_PWM;
    // stop timer
    TCCR1B = 0;
    // TOP for PWM, full 16 Bit
    ICR1 = 0xFFFF;
    // prescaler 1 -> ~122 Hz PWM frequency
    TCCR1B = (1 << WGM12) | (1 << WGM13) | 1;
 
    pwm_up_down (pwmtable_16, 256, delay);
}
 
int main (void)
{
    int8_t i;
    // delay in milliseconds for one fading step
    int16_t step_time = 400;
 
    // LED uses OC1A
    DDRD |= 1 << PD5;
 
    // test all fading routines
 
    while (1)
    {
        for (i=0; i<3; i++) pwm_8_4 (step_time);
        my_delay (1000);
        
        for (i=0; i<3; i++) pwm_8_8 (step_time/2);
        my_delay (1000);    
        
        for (i=0; i<3; i++) pwm_8_16 (step_time/4);
        my_delay (1000);
        
        for (i=0; i<3; i++) pwm_8_32 (step_time/8);
        my_delay (1000);
        
        for (i=0; i<3; i++) pwm_10_64 (step_time/16);
        my_delay (1000);
        
        for (i=0; i<3; i++) pwm_16_256 (step_time/16);
        my_delay (1000);
    }
 
    return 0;
}

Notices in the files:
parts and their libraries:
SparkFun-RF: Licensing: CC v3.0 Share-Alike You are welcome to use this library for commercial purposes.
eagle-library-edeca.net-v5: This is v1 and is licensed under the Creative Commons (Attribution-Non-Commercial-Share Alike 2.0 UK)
